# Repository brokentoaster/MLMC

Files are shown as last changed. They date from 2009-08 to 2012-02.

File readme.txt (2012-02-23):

The MLMC is a smart LED matrix module that can be chained to produced a scrolling display. I call it smart because a display made of these modules can be extended without changing either the firmware on the module controller or the firmware on the display controller. Each individual module will take care of refreshing its section of the display in a very power efficient way. When new data is sent to the display old data is passed along the chain from one module to the next. This serial shifting action makes building an arbitrary length scrolling display very simple to implement.

The LED matrix itself is hosted on a separate PCB to the module control circuitry. This separation makes it is simple to adapt the module to other LED matrices without changing the controller PCB or firmware. If you were producing a number of different sized displays you could use the same controller PCB for a module made from a 16 by 16 LED matrices as you might for a large module made using 16 by 16 individual 10mm LEDs.

More information can be found at http://www.brokentoaster.com/mlmc/ and http://www.brokentoaster.com/blog/?s=mlmc

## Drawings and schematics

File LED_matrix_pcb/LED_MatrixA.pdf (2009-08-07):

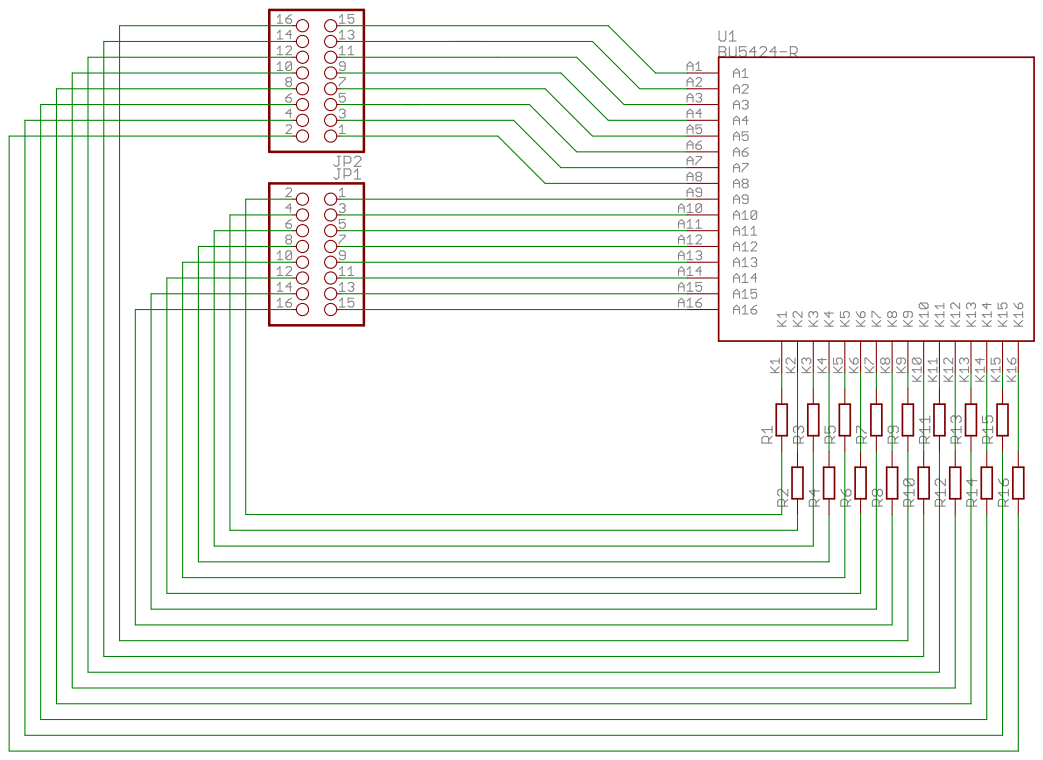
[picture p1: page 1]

07/08/2009 6:20PM f=0.62 /Users/nick/Documents/Electronics/eagle/LED_matrix_pcb/LED_MatrixA.sch (Sheet: 1/1)

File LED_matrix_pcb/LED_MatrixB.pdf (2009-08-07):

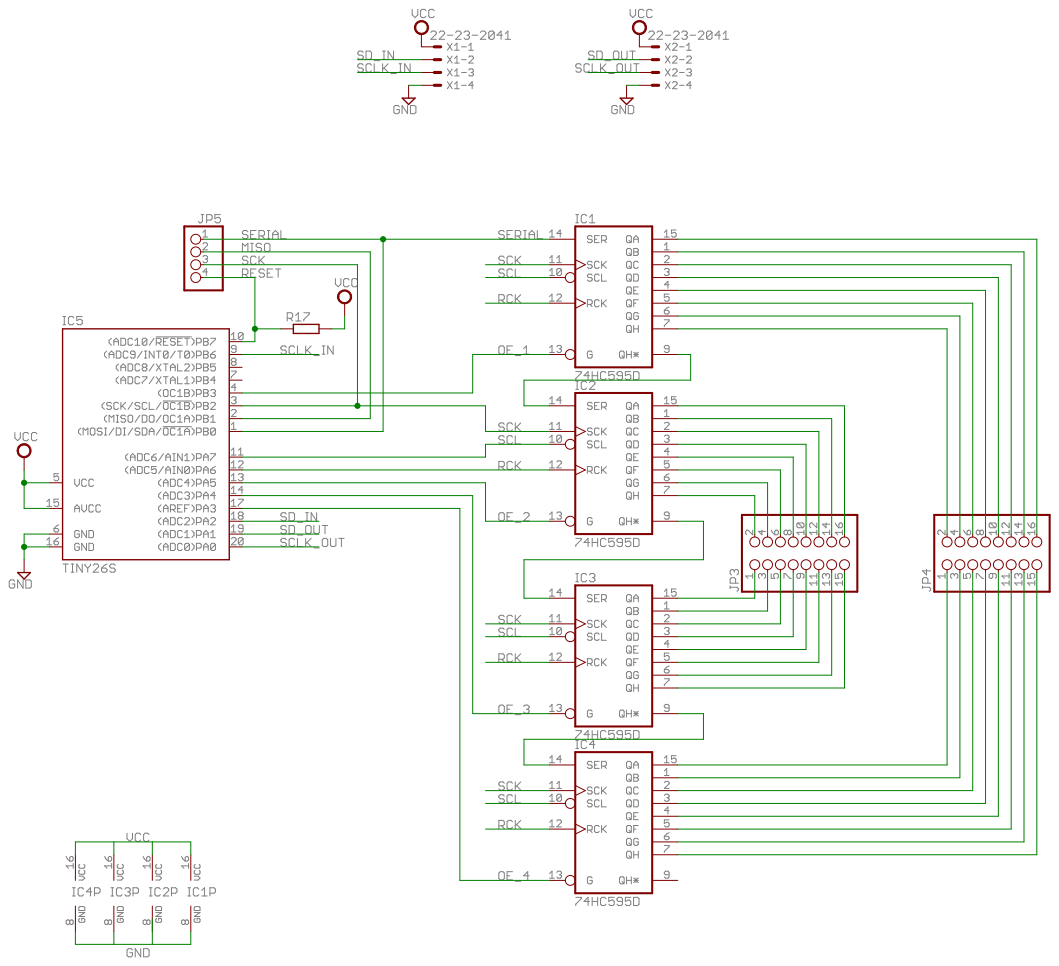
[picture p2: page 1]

07/08/2009 6:19PM f=0.62 /Users/nick/Documents/Electronics/eagle/LED_matrix_pcb/LED_MatrixB.sch (Sheet: 1/1)

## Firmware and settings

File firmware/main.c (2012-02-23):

/**
 * @file    main.c
 * @author  Nick Lott <nick.lott@gmail.com>
 * @version 1.0
 *
 * @section LICENSE
 *
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
 * @section DESCRIPTION
 *
 * The Main operating loop for the LED_MATRIX MODULE
 */


#include <avr/io.h>
#include <avr/interrupt.h>
#include <inttypes.h>
#include <util/delay.h>
#include <avr/sleep.h>

#ifdef USE_TEST_FUNCTIONS
#include "fontset0.h"
#endif

// PORT A  
#define SCLCK_OUT   PA0  ///< Serial clock output to next module
#define SD_OUT      PA1  ///< Serial data output to next module
#define SD_IN       PA2  ///< Serial data input from previous module 
#define OE4         PA3  ///< Output enable 4th shift register
#define OE3         PA4  ///< Output enable 3rd shift register
#define OE2         PA5  ///< Output enable 2nd shift register
#define RCK         PA6  ///< Register Clock for the shift registers
#define SCL         PA7  ///< Master Clear for all SRs

// PORT B
#define SERIAL      PB0  ///< Serial out to Shift Registers (USI)
#define MISO        PB1  ///< MISO for SPI Bus
#define SCK         PB2  ///< SCK for shift registers (USI)
#define OE1         PB3  ///< Output enable 1st shift register
#define DEBUG       PB4  ///< Debug trigger
#define UNUSED_PB5  PB5  ///< Not used
#define SCLCK_IN    PB6  ///< clk from previous module (INT0)
#define UNUSED_PB7  PB7  ///<  used by the Reset pin


/// Debug macros:
// Toggle the DEBUGPIN on port B
// From page 55 of datasheet for ATTiny261 (2588E–AVR–08/10)
// "writing a logic one to a bit in the PINx Register, will result in a toggle in the corresponding
// bit in the Data Register"
#define DEBUG_TRIGGER PINB = (1<<DEBUG)


// For FAST USI
// Cannot use the HW USI as PB0 is DI not DO as expected.
// with a mod it may work but would break programming. (works)
// TODO: Correct this on V2 of the PCB
#define USICLK_L  (1<<USIWM0)|(0<<USICS0)|(1<<USITC)
#define USICLK_H  (1<<USIWM0)|(0<<USICS0)|(1<<USICLK)|(1<<USITC)
#define HW_SPI 0    		        ///< set to 1 to use the fast inbuilt USI interface 5x faster. 7uS vs 32us
#define SW_SPI_FAST 0			///< use a nasty looking but as fast as possible SPI routine 20uS vs 32us
#define REVERSE_BYTE_USE_LOOKUP 0	///< use a 256 byte lookup tabel instead of calculating the reversed bit ordered byte

#define SOUT_DELAY_US 10        ///< us to wait in the clock cycle for Send_byte_next_module routine

#define FRAME_RESET_TIMEOUT 4 	///< number of screen refresh frames to wait before reseting serial interface
							    ///< This calculates to 20mS if refresh timer is running at 2.5kHz

#define BUFFERSIZE 32  				 		///< Size of ring buffer should be a power of 2
volatile uint8_t buffer[BUFFERSIZE]; 		///< Buffer to contain the 256 bits on the screen.
volatile uint8_t buffer_index;       		///< pointer to current start of buffer.
volatile uint16_t serial_in_buffer;  		///< buffer for next word currently being clocked in
volatile uint16_t serial_out_buffer; 		///< buffer for last word currently being clocked out
volatile uint8_t serial_in_index;    		///< bit of word currently being clocked in or out of the module

volatile uint16_t time_since_last_bit=0; 	///< counter how many timer periods have elapsed since last edge
volatile uint8_t last_clock_width=0;		///< timed value for last clock width

volatile uint8_t global_flags;				///< global variable for flags
#define FLAG_TIMER 			0 				///< flag to indicate the regular refresh timer has elapsed
#define FLAG_BUFFER_FULL 	1 				///< flag to indicate a word has been received on input
#define FLAG_EDGE			2				///< an edge was detected onthe serial input clock

#define CLEAR_FLAG(b) 		(global_flags &= ~(1<<b))
#define SET_FLAG(b)			(global_flags |= (1<<b))
#define FLAG_IS_SET(b)		(global_flags & (1<<b))
#define FLAG_IS_CLEAR(b) 	((global_flags & (1<<b)) == 0)


#define SET_OR_CLEAR_BIT_IF_BIT_IS_SET(bit,port,pin,data) \
	((1<<(bit)) & (data) ) ? ((port) |= (1<<(pin))) : ((port) &= ~(1<<(pin)));


// Hardware Initialisation functions
void init_pins (void);
void init_timer0(void);
void init_timer1(void);
void init_usi(void);
void init_serial_input(void);

//  Shift register functions
void usi_send_byte(uint8_t data);
void usi_send_byte_LSB_FIRST(uint8_t data);
void enable_output( void );
void disable_ouput(void);

// screen updating functions
void update_screen(void);
void draw_col(uint8_t column, uint8_t upper_byte, uint8_t lower_byte);
uint8_t reverse_byte (uint8_t byte);
void clock_new_ouput(void);

// Serial and buffer functions
void insert_word_into_buffer(void);



/**
 * Main operating loop for the software
 */
int main(void)
{
	//
	// Hardware Initialisation
	//
	init_pins();
	init_usi();
	init_serial_input();
	init_timer0();
	init_timer1();
	enable_output();

	//reduce power consumption in unused peripherals
	// (minor change to current consumption)
	 PRR=(0<<PRTIM1)|(0<<PRTIM0)|(0<<PRUSI)|(1<<PRADC);

	//
	// Main Loop
    //
	for(;;){
        // have we got a new word?
		if (FLAG_IS_SET(FLAG_BUFFER_FULL)){
			insert_word_into_buffer();                                          //save the word that just came in.
		}

		// Is it time to update the screen?
		if (FLAG_IS_SET(FLAG_TIMER)){
			CLEAR_FLAG(FLAG_TIMER);                                             // reset the timer flag
			update_screen();                                                    // draw a single column of the screen buffer

			// Do some other house keeping after updating the screen.
			time_since_last_bit++;                                              // increment our refresh timer/counter (2.5khz)

            // this is to abort the buffer if we have received a partial word but
            // no clocks for some time. This should mean that the screens will
            // synchronise if no data is received for some time.
            // It should also make the system more robust should spurious clocks
            // be received due to noise.
			if ((time_since_last_bit == FRAME_RESET_TIMEOUT)&& FLAG_IS_CLEAR(FLAG_BUFFER_FULL)){
				serial_in_index = 16;                                           // reset buffer word bit pointer
				serial_in_buffer = 0x0000;                                      // clear buffer word
			}
		}

        // Go to sleep (timers still running)
		set_sleep_mode(SLEEP_MODE_IDLE);
		sleep_mode();

	}

	return 0;   /* never reached */
}



/**
 * Initialise the I/O pins
 *
 */
void init_pins (void)
{

    // set shift register output-enable and clear pins High (active low)
    PORTA = (0<<SCLCK_OUT)|(0<<SD_OUT)|(0<<SD_IN)|(1<<OE4)|(1<<OE3)|(1<<OE2)|(0<<RCK)|(1<<SCL);
    PORTB = (0<<SCLCK_IN)|(1<<OE1)|(0<<SCK)|(0<<MISO)|(0<<SERIAL)|(1<<DEBUG);
    
    // Set the direction of pins on Port A 
    DDRA = (1<<SCLCK_OUT)|(1<<SD_OUT)|(0<<SD_IN)|(1<<OE4)|(1<<OE3)|(1<<OE2)|(1<<RCK)|(1<<SCL);
    
    // Set the direction of pins on Port B
    DDRB = (0<<SCLCK_IN)|(1<<OE1)|(1<<SCK)|(1<<MISO)|(1<<SERIAL)|(1<<DEBUG);
}



/** 
 * Initialise the Timer
 *
 * The timer is timer0 and uses the 8Mhz system clock to provide a 150 Hz update
 * rate for the screen.
 */
void init_timer0(void)
{
    // Timer Counter 0 control register A
    // 16 bit modelast_clock_width
    TCCR0A = (1<<TCW0)|(0<<ICEN0)|(0<<ICNC0)|(0<<ICES0)| (0<<ACIC0)|(0<<WGM00);
    
    // Timer Conter 0 Interrupt Mask Register
    // enable ouput compare A interrupt.
    TIMSK  |= (1<<OCIE0A);
    
    // TimerCounter0 control register B
    // reset the counter and set source to system clock with no prescaling.
    TCCR0B  = (0<<TSM)|(1<<PSR0)|(0<<CS02)|(0<<CS01)|(1<<CS00);
    
    // set counter to 0x1f40 or 8000 counts this should give a 1ms interval 
    // set counter to 0x0320 for 800 counts -> 100uS interval
    // set counter to 0x0640 for 1600 counts -> 200uS interval
    // set counter to 0x0C80 for 3200 counts -> 400uS interval (2.5Khz /16 cols  => 156H.25Hz Refresh
    OCR0B =0x0C;
    OCR0A =0x80 ;
    
    CLEAR_FLAG(FLAG_TIMER);


}



/**
 * Initialise the secondary Timer
 *
 * The timer is timer1 and uses the 8Mhz system clock to provide a 1MHZ counter
 * Used for timing pulse width of incoming clock signal.
 */
void init_timer1(void)
{
	// TCCR1A – Timer Counter 1 control register A
	TCCR1A = (0<<COM1A1)|(0<<COM1A0)|(0<<COM1B1)|(0<<COM1B0)|(0<<FOC1A)|(0<<FOC1B)|(0<<PWM1A)|(0<<PWM1B);

	// TCCR1B – Timer/Counter1 Control Register B
	// clocked at clk/8
	TCCR1B = (0<<PWM1X)|(0<<PSR1)|(0<<DTPS11)|(0<<DTPS10)|(0<<CS13)|(1<<CS12)|(0<<CS11)|(0<<CS10);

	// TCCR1C – Timer/Counter1 Control Register C
	TCCR1C = (0<<COM1A1S)|(0<<COM1A0S)|(0<<COM1B1S)|(0<<COM1B0S)|(0<<COM1D1)|(0<<COM1D0)|(0<<FOC1D)|(0<<PWM1D);

	// TCCR1D – Timer/Counter1 Control Register D
	// Normal counter mode
	TCCR1D = (0<<FPIE1)|(0<<FPEN1)|(0<<FPNC1)|(0<<FPES1)|(0<<FPAC1)|(0<<FPF1)|(0<<WGM11)|(0<<WGM10);

	// TCCR1E – Timer/Counter1 Control Register E
	TCCR1E = (0<<OC1OE5)|(0<<OC1OE4)|(0<<OC1OE3)|(0<<OC1OE2)|(0<<OC1OE1)|(0<<OC1OE0);

	// PLLCSR – PLL Control and Status Register
	// synchonous system clock is used.
	PLLCSR = (0<<LSM)|(0<<PCKE)|(0<<PLLE);

	// set top value
	OCR1C =0xff;


}



/**
 * Initialise the Serial bus
 *
 * The bus is used to talk to the shift registers. Once the 4 bytes have been
 * clocked out with SCK they must be clocked through with a +ve edge on RCK
 * if the OE is low then they will appear on the outputs. The USI can be used to 
 * clock the data out quickly.
 */
void init_usi(void)
{
    USICR = (0<<USISIE)|(0<<USIOIE)|(0<<USIWM1)|(1<<USIWM0)|(0<<USICS1)|(0<<USICS0)|(0<<USICLK)|(0<<USITC);
    
}



/** 
 * setup the incoming Serial interface ISR
 */
void init_serial_input(void)
{
    // reset buffesr 
    serial_in_index = 16;
    serial_in_buffer = 0;
    buffer_index =0;
    serial_out_buffer = 0;
    
    // rising edge gOCR1A = 0x00;enerates an interrupt
    // MCUCR |= (1<<ISC01)|(1<<ISC00);
    
    // any edge generates an interrupt
    MCUCR |= (0<<ISC01)|(1<<ISC00);
    
    // INT0 only
    GIMSK = (0<<INT1)|(1<<INT0)|(0<<PCIE1)|(0<<PCIE0);
    
    // enable global interrupts
    sei();
}




/** 
 * Serial input ISR
 *
 * This is triggered when a new edge has been detected on the input serial clock 
 * line. The bit will be clocked into the current buffer once 16 bits have been 
 * Received they will be move into the main buffer and the old bits clocked
 * out the serial out interface.
 * This simultaneously clocks out old data 
 * MSB is first.
 *
 * This ISR takes 12-15us on a rising edge while serial_in_index>2
 * On last rising edge the ISlast_clock_widthR takes 24us
 * Falling edges take 1.4us to complete
 * There is a delay of 3.6us to enter the ISR
 */
ISR(INT0_vect){
	//DEBUG_TRIGGER;

	// disable the last bit clock as we have just seen an edge
	TIMSK &= ~(1<<OCIE1A);

	// re-enable interrupts so the screen update can happen
    // .. \todo Shortening this whole ISR would be a better solution
	sei();

    // look for a rising edge
    if (PINB & (1<<SCLCK_IN)){
    	if( FLAG_IS_CLEAR(FLAG_BUFFER_FULL) ){
    		TCNT1 = 0x00;														// Reset Timer1
    		TIFR |= (1<<TOV1); // reset the overflow flag


			serial_in_index--;                                                  // move pointer to next bit

			// set bit in buffer
			if (PINA & (1<< SD_IN) ){
				serial_in_buffer |= (1<<serial_in_index);
			}
			PORTA &= ~( (1<<SCLCK_OUT));                                        // clear outgoing clock

			// set/clear bit on outgoing serial
			if (serial_out_buffer & (1<<serial_in_index)){
				PORTA |= (1<<SD_OUT);                                           // set data bit
			}else{
				PORTA &= ~(1<<SD_OUT);                                          // clear data bit
			}

			// set the flag if the buffer is full.
			if (serial_in_index == 0){
				SET_FLAG(FLAG_BUFFER_FULL);
			}
    	}
    }else{ // A falling edge
        PORTA |= (1<<SCLCK_OUT);                                                // set outgoing clock line
        time_since_last_bit=0;                                                  // reset our inter frame timer

		// save the clock period for use later.
		last_clock_width = TCNT1;

		// Reset Timer1
		TCNT1 = 0x00;

		// setup the Output compare value
		if (TIFR & (1<<TOV1)){
			OCR1A = 0xff;
		}else{
			OCR1A =last_clock_width ;
		}

		// enable the interrupt to clock out the last bit
		TIFR |= (1<<TOV1)|(1<<OCF1A ); 											// reset the overflow and interrupt flag
		asm volatile("nop\n\t"::);
		TIMSK |= (1<<OCIE1A );
    }
    //DEBUG_TRIGGER;

}



/**
 * Timer interrupt 
 *
 * This is use to update the screen periodically.
 * This ISR takes 768ns between debug triggers
 * Frequency is ~ 4.8Khz (208us period)
 */
ISR(TIMER0_COMPA_vect)
{
  //  DEBUG_TRIGGER;
    TCNT0H=0;
    TCNT0L=0;
    SET_FLAG(FLAG_TIMER);
   // DEBUG_TRIGGER;
}



/**
 * Timer1 interrupt
 *
 * This ISR is used to clock out the final bit of a word if no new bit has been
 * received. It then disables it self to give a "one-shot" action.
 */
ISR(TIMER1_COMPA_vect)
{
    PORTA &= ~(1<<SCLCK_OUT);			                            			// clear clock
    TIMSK &= ~(1<<OCIE1A);														// disable the interrupt
}



/**
 * Send a single byte on the USI bus to the shift registers
 * 
 * This sends the 8 bit data byte out the SERIAL line and clocks the SCK with 
 * each byte. This routine has been optimised for speed.
 */
 void usi_send_byte(uint8_t data ///< 8 bit data to be sent
                   )
{
#if (HW_SPI==1) 
    USIDR = data;
    USICR = USICLK_L; // bit 7 , MSB
    USICR = USICLK_H;
    USICR = USICLK_L; // bit 6
    USICR = USICLK_H;
    USICR = USICLK_L; // bit 5
    USICR = USICLK_H;
    USICR = USICLK_L; // bit 4
    USICR = USICLK_H;
    USICR = USICLK_L; // bit 3
    USICR = USICLK_H;
    USICR = USICLK_L; // bit 2
    USICR = USICLK_H;
    USICR = USICLK_L; // bit 1
    USICR = USICLK_H;
    USICR = USICLK_L; // bit 0 , LSB
    USICR = USICLK_H;
#else
  #if (SW_SPI_FAST==0) // this gives 940ns and 870ns per fist and following bits
    uint8_t temp;
    uint8_t i ;
    temp = data;
    for (i=0;i<8;i++){
         PORTB &= ~(1<<SCK);                                                     // clear clock line

         if (temp & 0x80){
             PORTB |= (1<<SERIAL);                                               // set data bit
         }else{
             PORTB &= ~(1<<SERIAL);                                              // clear data bit
         }

         PORTB |= (1<<SCK);                                                      // set clock line
         temp <<= 1;                                                             // shift along by one
     }
  #else // this gives 610ns for all bits
    // assume the clock line is low to begin with (set in init routine)
    ((1<<7) & data) ? (PORTB |= (1<<SERIAL)) : (PORTB &= ~(1<<SERIAL));      	// clear or set data bit
    PINB = (1<<SCK);                                                       		// set clock line
    PINB = (1<<SCK);                                                       		// clear clock line
    ((1<<6) & data) ? (PORTB |= (1<<SERIAL)) : (PORTB &= ~(1<<SERIAL));      	// clear or set data bit
    PINB = (1<<SCK);                                                       		// set clock line
    PINB = (1<<SCK);                                                       		// clear clock line
    ((1<<5) & data) ? (PORTB |= (1<<SERIAL)) : (PORTB &= ~(1<<SERIAL));      	// clear or set data bit
    PINB = (1<<SCK);                                                      	 	// set clock line
    PINB = (1<<SCK);                                                       		// clear clock line
    ((1<<4) & data) ? (PORTB |= (1<<SERIAL)) : (PORTB &= ~(1<<SERIAL));      	// clear or set data bit
    PINB = (1<<SCK);                                                       		// set clock line
    PINB = (1<<SCK);                                                       		// clear clock line
    ((1<<3) & data) ? (PORTB |= (1<<SERIAL)) : (PORTB &= ~(1<<SERIAL));      	// clear or set data bit
    PINB = (1<<SCK);                                                       		// set clock line
    PINB = (1<<SCK);                                                       		// clear clock line
    ((1<<2) & data) ? (PORTB |= (1<<SERIAL)) : (PORTB &= ~(1<<SERIAL));      	// clear or set data bit
    PINB = (1<<SCK);                                                       		// set clock line
    PINB = (1<<SCK);                                                       		// clear clock line
    ((1<<1) & data) ? (PORTB |= (1<<SERIAL)) : (PORTB &= ~(1<<SERIAL));      	// clear or set data bit
    PINB = (1<<SCK);                                                       		// set clock line
    PINB = (1<<SCK);                                                       		// clear clock line
    ((1<<0) & data) ? (PORTB |= (1<<SERIAL)) : (PORTB &= ~(1<<SERIAL));      	// clear or set data bit
    PINB = (1<<SCK);                                                       		// set clock line
  #endif
    PORTB &= ~( (1<<SCK)|(1<<SERIAL) );                                         // clear clock and data line
#endif
}



/**
 * Send a single byte LSB first on the USI bus to the shift registers
 *
 * This sends the 8 bit data byte out the SERIAL line and clocks the SCK with
 * each byte. This routine has been optimised for speed.
 */
  void usi_send_byte_LSB_FIRST(uint8_t data ///< 8 bit data to be sent
                   )
{
#if (HW_SPI==1)
	  uint8_t reversed_byte;

#if (REVERSE_BYTE_USE_LOOKUP==1)
	  reversed_byte = pgm_read_byte(reverse_lookup+data);
#else
	  reversed_byte = reverse_byte( data);
#endif

    USIDR = reversed_byte;
    USICR = USICLK_L; // bit 7 , MSB
    USICR = USICLK_H;
    USICR = USICLK_L; // bit 6
    USICR = USICLK_H;
    USICR = USICLK_L; // bit 5
    USICR = USICLK_H;
    USICR = USICLK_L; // bit 4
    USICR = USICLK_H;
    USICR = USICLK_L; // bit 3
    USICR = USICLK_H;
    USICR = USICLK_L; // bit 2
    USICR = USICLK_H;
    USICR = USICLK_L; // bit 1
    USICR = USICLK_H;
    USICR = USICLK_L; // bit 0 , LSB
    USICR = USICLK_H;
#else

#if (SW_SPI_FAST==0)
    uint8_t temp;
    uint8_t i ;

    temp = data;

    for (i=0;i<8;i++){
        PORTB &= ~(1<<SCK);                                                     // clear clock line

        if (temp & 0x01){
            PORTB |= (1<<SERIAL);                                               // set data bit
        }else{
            PORTB &= ~(1<<SERIAL);                                              // clear data bit
        }

        PORTB |= (1<<SCK);                                                      // set clock line
        temp >>= 1;                                                             // shift along by one
    }
#else // this gives 620ns for all bits

   // PINB = (1<<SCK);                                                       	// toggle clock line
    SET_OR_CLEAR_BIT_IF_BIT_IS_SET(0,PORTB,SERIAL,data);						// clear or set data bit
    PINB = (1<<SCK);                                                       		// set clock line
    PINB = (1<<SCK);                                                       		// toggle clock line
    SET_OR_CLEAR_BIT_IF_BIT_IS_SET(1,PORTB,SERIAL,data);						// clear or set data bit
    PINB = (1<<SCK);                                                       		// set clock line
    PINB = (1<<SCK);                                                       		// toggle clock line
    SET_OR_CLEAR_BIT_IF_BIT_IS_SET(2,PORTB,SERIAL,data);						// clear or set data bit
    PINB = (1<<SCK);                                                       		// set clock line
    PINB = (1<<SCK);                                                       		// toggle clock line
    SET_OR_CLEAR_BIT_IF_BIT_IS_SET(3,PORTB,SERIAL,data);						// clear or set data bit
    PINB = (1<<SCK);                                                       		// set clock line

    PINB = (1<<SCK);                                                       // toggle clock line
    SET_OR_CLEAR_BIT_IF_BIT_IS_SET(4,PORTB,SERIAL,data);						// clear or set data bit
    PINB = (1<<SCK);                                                       // set clock line
    PINB = (1<<SCK);                                                       // toggle clock line
    SET_OR_CLEAR_BIT_IF_BIT_IS_SET(5,PORTB,SERIAL,data);						// clear or set data bit
    PINB = (1<<SCK);                                                       // set clock line
    PINB = (1<<SCK);                                                       // toggle clock line
    SET_OR_CLEAR_BIT_IF_BIT_IS_SET(6,PORTB,SERIAL,data);						// clear or set data bit
    PINB = (1<<SCK);                                                       // set clock line
    PINB = (1<<SCK);                                                       // toggle clock line
    SET_OR_CLEAR_BIT_IF_BIT_IS_SET(7,PORTB,SERIAL,data);						// clear or set data bit
    PINB = (1<<SCK);                                                       // set clock line
#endif

    PORTB &= ~( (1<<SCK)|(1<<SERIAL) );                                         // clear clock and data line

#endif
}



/**
 * Enable the Shift registers output
 */
void enable_output( void )
{
    PORTA &=~((1<<OE4)|(1<<OE3)|(1<<OE2));
    PORTB &=~(1<<OE1);

}



/**
 * Disable the output from the shift registers
 */
void disable_ouput(void)
{
    PORTA |= (1<<OE4)|(1<<OE3)|(1<<OE2);
    PORTB |= (1<<OE1);
}



/** 
 * Shift the data to the ouputs of the shift registers
 *
 * Cycle the RCK (register clock) on the shift register to latch the data 
 * from the data register to the actual outputs
 */
void clock_new_ouput(void)
{
    PINA = (1<<RCK);                                                            // Toggle this pin 0->1
    PINA = (1<<RCK);                                                            // Toggle this pin 1->0
}
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

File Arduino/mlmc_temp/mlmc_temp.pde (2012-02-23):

/* ----------------------------------------------------------------------
 * MAX6675 stuff
 * This section takes care of reading a Temperature from the thermocouple
 */
#include <MAX6675.h>
int LED1 = 13;              // Status LED Pin

int power = 12;
int SCK = 11;                // SCK pin of MAX6675
int CS = 10;                // CS pin on MAX6675
int SO = 9;                // SO pin of MAX6675
int gnd =8;                // IF

int units = 1;              // Units to readout temp (0 = ˚F, 1 = ˚C)
float error = -15.0;        // Temperature compensation error (measured)
float temperature = 0.0;    // Temperature output variable
/*------------------------------------------------------------------------
*/



/* ----------------------------------------------------------------------
 * MLMC stuff
 * Select the fonts and hardware details for the MLMC dis[play here
 */
//#include "font_ttuf1.h"
#include "fontset0.h"
//#include "fontset2.h"
#define FONT_OFFSET 33
int dataPin = 2;
int clockPin = 3;
int spidelay =75;
//const int slaveSelectPin = 10;
int gInterColDelay=0 ;
int gInterCharDelay;

// Initialize the MAX6675 Library for our chip
MAX6675 temp0(CS,SO,SCK,units,error);
/*------------------------------------------------------------------------
*/


/* ----------------------------------------------------------------------
*/
void Send_byte( char data ///< 8 bit dataPin to be sent
              ) {
    uint8_t temp;
    uint8_t i,j ;

    temp = data;

    for (i=0; i<8; i++) {
        digitalWrite(clockPin, LOW);

        if (temp & (1<<7)) {
            digitalWrite(dataPin, HIGH);
        } else {
            digitalWrite(dataPin, LOW);
        }

        delayMicroseconds(spidelay);
        digitalWrite(clockPin,HIGH);  // clockPin the dataPin out
        delayMicroseconds(spidelay);

        temp <<= 1;                                // shift allong by one
    }

    digitalWrite(clockPin, LOW);
    digitalWrite(dataPin, LOW);
}

char reverse(char b) {
    return  (b * 0x0202020202ULL & 0x010884422010ULL) % 1023;
}

// print char to the mlmc display one column at a time
// any leading blank columns of the characters are skipped
// if the char is outside the fontset then
void mlmc_print_char_double(char c, char c2) {
    char i,j,k,l;
    char tdata;
    char data;
    char not_leading;
    char data_array[32];

    for (i=0; i<32; i++) data_array[i]=0;

    k=0;

    // do the top row
    if (c >= FONT_OFFSET) {

        not_leading =0;

        for (i=0; i < fontSet1[1]; i++) {

            data = pgm_read_byte( fontSet1 + (( c - FONT_OFFSET ) * fontSet1[1] ) + i + 3 );

            if (data !=00 || not_leading == 1) {
                // if not a leading blank column then send the column to the display
                not_leading = 1;
                k++;
                data_array[k++]= data;
            }
        }
    } else {

        // send a blank space
        for (i=0; i<fontSet1[1]; i++) {
            k+=2;
        }
    }

//    do the bottom row
    l=0;
    if (c2 >= FONT_OFFSET) {

        not_leading =0;

        for (i=0; i < fontSet1[1]; i++) {

            data = pgm_read_byte( fontSet1 + (( c2 - FONT_OFFSET ) * fontSet1[1] ) + i + 3 );

            if (data !=00 || not_leading == 1) {
                // if not a leading blank column then send the column to the display
                not_leading = 1;
                data_array[l++]= data;   // invert bottom half of screen
                l++;

            }
        }
    } else {

        // send a blank space
        for (i=0; i<fontSet1[1]; i++) {
            l+=2;
        }
    }

    // send out the bytes
    if (l>k) k=l;
    l=0;


    for (l=0; l<k;) {
        Send_byte(data_array[l++]); // invert bottom half of screen
        Send_byte(data_array[l++]);
        delay (gInterColDelay);
    }

    // blank column between characters
    Send_byte(0);
    Send_byte(0);
}

// print char to the mlmc display one column at a time
// any leading blank columns of the characters are skipped
// if the char is outside the fontset then
void mlmc_print_char(char c) {
    char i,j;
    char tdata;
    char data;
    char not_leading;

    if (c >= FONT_OFFSET) {

        not_leading =0;

        for (i=0; i < fontSet1[1]; i++) {

            data = pgm_read_byte( fontSet1 + (( c - FONT_OFFSET ) * fontSet1[1] ) + i + 3 );

            if (data !=00 || not_leading == 1) {
                // if not a leading blank column then send the column to the display
                not_leading = 1;
                Send_byte( ~data); // invert bottom half of screen
                Send_byte( data);
                delay (gInterColDelay);
            }
        }
    } else {

        // send a blank space
        for (i=0; i<fontSet1[1]; i++) {
            Send_byte(0xFF); // invert bottom half of screen
            Send_byte(0);
            delay (gInterColDelay);
        }
    }

    // blank column between characters
    Send_byte(0xFF);
    Send_byte(0);
}


void mlmc_clearscreen() {
    char i;
    for (i=0; i<14; i++) {
        mlmc_print_char(32);
    }
}

void mlmc_print(char *c) {
    int i = 0;

    while (c[i]) {
        mlmc_print_char(c[i]);
        i++;
    }
    delay(gInterCharDelay);
}

/** Step through two strings and print a char from each to the screen

If one string is longer than the other then blank spaces will be printed
*/
void mlmc_print_double(char *c,char *c2) {
    int i = 0;
    char flag = 0;

    while (flag<3) {
        if (c[i]==0 or (flag & (1<<0)))
            flag  |= (1<<0);
        if (c2[i]==0 or (flag & (1<<1)))
            flag |= (1<<1);

        switch (flag) {
            case 0:
                mlmc_print_char_double(c[i],c2[i]);
                break;
            case 1:
                mlmc_print_char_double(0x00,c2[i]);
                break;
            case 2:
                mlmc_print_char_double(c[i],0x00);
                break;
        }
        i++;
    }
    delay(gInterCharDelay);
}
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

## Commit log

2009-08-07 Initial import
    [git-p4: depot-paths = "//depot/LED_Matrix_Module/": change = 14]
    [LED_MatrixA.brd, LED_MatrixA.sch, LED_MatrixB.brd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]
2009-08-14 add data sheet
    [git-p4: depot-paths = "//depot/LED_Matrix_Module/": change = 16]
2009-08-14 working scroller
    [git-p4: depot-paths = "//depot/LED_Matrix_Module/": change = 17]
2009-08-14 not working time for bed. need to improve ISR
    [git-p4: depot-paths = "//depot/LED_Matrix_Module/": change = 18]
    [main.c]
2009-08-14 eod
    [git-p4: depot-paths = "//depot/LED_Matrix_Module/": change = 19]
2009-08-21 now simultaneously clocking out as new data is clocked in. ISR is very slow needs 1ms clock pulse widths for reliable data transmission. consider changing to eight bit routines.
    [git-p4: depot-paths = "//depot/LED_Matrix_Module/": change = 20]
2009-08-23 Display update is now single column at a time, triggered by a 1ms interrupt on timer 0
    [git-p4: depot-paths = "//depot/LED_Matrix_Module/": change = 21]
2011-01-23 Unknown LED Matix Changes
    [git-p4: depot-paths = "//depot/LED_Matrix_Module/": change = 64]
2011-05-15 Initial attempts at a frame reset. didn't work need to use timer1 to impliment the frame reset added eclipse project files.
    [git-p4: depot-paths = "//depot/LED_Matrix_Module/": change = 79]
    [main.c]
2011-06-26 removed binary object files. updated the website
    [git-p4: depot-paths = "//depot/LED_Matrix_Module/": change = 84]
2011-10-02 Fixed bug with missing last column of display. Further attempts to fix synchtonisation issues.
    [git-p4: depot-paths = "//depot/LED_Matrix_Module/": change = 86]
    [main.c]
2011-10-03 Fixed synchronisation error with third module due to clock line beein inverted as final bit was not being clocked out. (clock was left high).
    [git-p4: depot-paths = "//depot/LED_Matrix_Module/": change = 87]
    [main.c]
2011-10-03 Comment and layout changes only
    [git-p4: depot-paths = "//depot/LED_Matrix_Module/": change = 88]
2011-10-04 added some todos
    [git-p4: depot-paths = "//depot/LED_Matrix_Module/": change = 89]
2011-10-04 added some power saving changes. Tested using PLL as clock but slow comms was lost from arduino. Might be able to check to find out why if we need better performance later.
    minimal performance increase from the sleep modes as only going into idle mode as we want to be woken up by the timer.
    [git-p4: depot-paths = "//depot/LED_Matrix_Module/": change = 90]
2011-10-05 comments
    [git-p4: depot-paths = "//depot/LED_Matrix_Module/": change = 91]
2011-10-05 broken evertything?
    [git-p4: depot-paths = "//depot/LED_Matrix_Module/": change = 92]
    [main.c]
2011-10-05 using timer1 to clock out last bit
    [git-p4: depot-paths = "//depot/LED_Matrix_Module/": change = 93]
2011-10-15 Fixed flickering bright columns in screen. Needed to allow nested inturrupts.
    [git-p4: depot-paths = "//depot/LED_Matrix_Module/": change = 94]
    [main.c]
2011-10-15 code tidy up. Moved testing vunctions out of the way and adde dprototypes for used functions
    [git-p4: depot-paths = "//depot/LED_Matrix_Module/": change = 95]
2011-10-16 Some optimizations to the usi routines although some bluriness can now be seen on right hand side of screen?!
    [git-p4: depot-paths = "//depot/LED_Matrix_Module/": change = 96]
2011-10-16 Added c program to generate the look up tables used in main.c
    [git-p4: depot-paths = "//depot/LED_Matrix_Module/": change = 97]
2011-10-19 Updated board for rev B. Initial attempt.
    [git-p4: depot-paths = "//depot/LED_Matrix_Module/": change = 98]
    [LED_MatrixB.brd, LED_MatrixB.sch]
2011-10-19 Rev B changes
    [git-p4: depot-paths = "//depot/LED_Matrix_Module/": change = 99]
2011-11-03 Integration change.
    [git-p4: depot-paths = "//depot/LED_Matrix_Module/": change = 100]
2011-11-03 Rename/move file(s)
    [git-p4: depot-paths = "//depot/LED_Matrix_Module/": change = 101]
2011-11-03 more optimizations. still screen corruption
    [git-p4: depot-paths = "//depot/LED_Matrix_Module/": change = 102]
2011-11-04 Fixed glitch using lookup tables for columns. current column wasn't being set correctly
    [git-p4: depot-paths = "//depot/LED_Matrix_Module/": change = 103]
    [main.c]
2012-02-14 placed fontset include into testing functions. Will not develop onboard fonts until after version 1 is released
    [git-p4: depot-paths = "//depot/LED_Matrix_Module/": change = 104]
2012-02-20 Added a todo about shortening the ISR :)
    [main.c]
2012-02-20 tidied up the PCB directories
2012-02-23 Added Arduino examples. Most of these can be removed but these are all the ones from the sketch book.
2012-02-23 Changed port defines to use PB0 style rather than 0 style for pin numbers

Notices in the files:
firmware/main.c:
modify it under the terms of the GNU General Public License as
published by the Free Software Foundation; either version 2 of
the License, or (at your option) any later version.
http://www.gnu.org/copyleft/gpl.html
